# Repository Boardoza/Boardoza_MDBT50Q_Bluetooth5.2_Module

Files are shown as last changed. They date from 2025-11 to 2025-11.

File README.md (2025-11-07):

# Boardoza MDBT50Q Bluetooth Module

The **Boardoza MDBT50Q Bluetooth Module** is a high-performance wireless communication module based on the **Raytac MDBT50Q** series, featuring the **Nordic Semiconductor nRF52833 SoC** and supporting **Bluetooth 5.2**. This compact and power-efficient module is designed for applications requiring robust, long-range, and low-power wireless connectivity — such as IoT devices, smart home products, wearables, and industrial sensors.

It offers a UART communication interface and flexible configuration options, including selectable RC oscillators and hardware flow control. The MDBT50Q ensures reliability and ease of integration for developers working on BLE-enabled projects.

## [Click here to purchase!](https://www.ozdisan.com/p/gelistirme-kitleri-ve-aksesuarlari-617/boardoza-boardoza-mdbt50q-1202711)

|Front Side|Back Side|
|:---:|:---:|
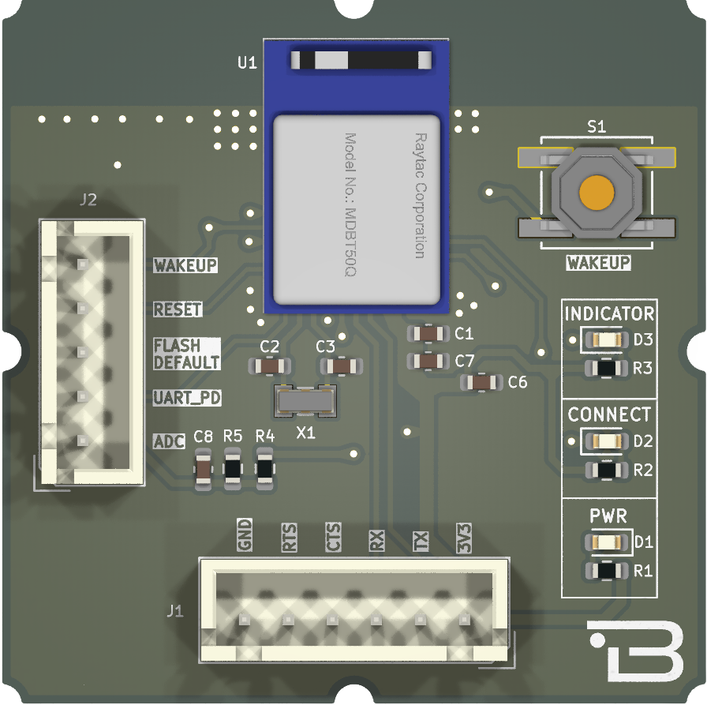
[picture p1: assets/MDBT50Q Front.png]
Front
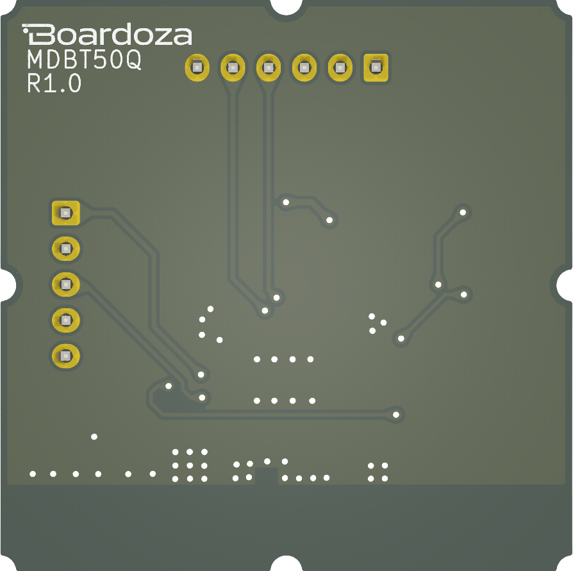
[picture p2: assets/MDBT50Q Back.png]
Back
|||

---

## **Key Features**

- **Bluetooth 5.2 Support:** Enables high-speed, low-energy communication with extended range.  
- **Nordic nRF52833 SoC:** Built-in ARM® Cortex®-M4 CPU with FPU operating up to 64 MHz.  
- **Low Power Consumption:** Optimized for long battery life in portable or IoT devices.  
- **Flexible UART Interface:** Configurable enable/disable control and flow control options.  
- **Selectable Clock Source:** Supports external or internal 32.768 kHz RC oscillator.  
- **512 KB RAM:** Large memory for advanced BLE applications.  

---

## **Technical Specifications**

**Manufacturer:** Raytac Corporation  
**Model:** MDBT50Q  
**Core Chip:** Nordic nRF52833 SoC (ARM® Cortex®-M4F)  
**Input Voltage:** 3.3V  
**Voltage Input Type:** Standard 6-pin header (2.54mm pitch)  
**Communication Interface:** UART  
**Bluetooth Version:** 5.2 (Low Energy)  
**Flash Memory:** 512 KB  
**RAM:** 128 KB  
**Antenna:** Integrated PCB antenna  
**Operating Frequency:** 2.4 GHz ISM band  
**Operating Temperature:** -40°C ~ +85°C  
**Extended Operating Temperature:** -40°C ~ +105°C 
**Board Dimensions:** 40mm x 40mm  
**Functions:** Bluetooth Low Energy Wireless Module  

---

## **Board Pinout**

### **( J1 ) Power & UART Connector**

| Pin Number | Pin Name | Description |
|:---:|:---:|---|
| 1 | 3V3 | Positive Power Supply |
| 2 | UART_TX | UART Transmitter |
| 3 | UART_RX | UART Receiver |
| 4 | UART_CTS | CTS, Clear to Send |
| 5 | UART_RTS | RTS, Request to Send |
| 6 | GND | Ground |

### **( J2 ) Control Connector**

| Pin Number | Pin Name | Description |
|:---:|:---:|---|
| 1 | ADC | 10-bit ADC input, updated every 200ms |
| 2 | UART_PD | Active-high with internal pull-up to disable UART hardware (default: disabled) |
| 3 | FLASH_DEFAULT | Active-low (0.48s ≤ Low ≤ 1s) triggers system reset to default configuration |
| 4 | RESET | Active-low system hardware reset |
| 5 | WAKEUP | Wake-up control output from deep sleep mode |

---

## **Board Dimensions**

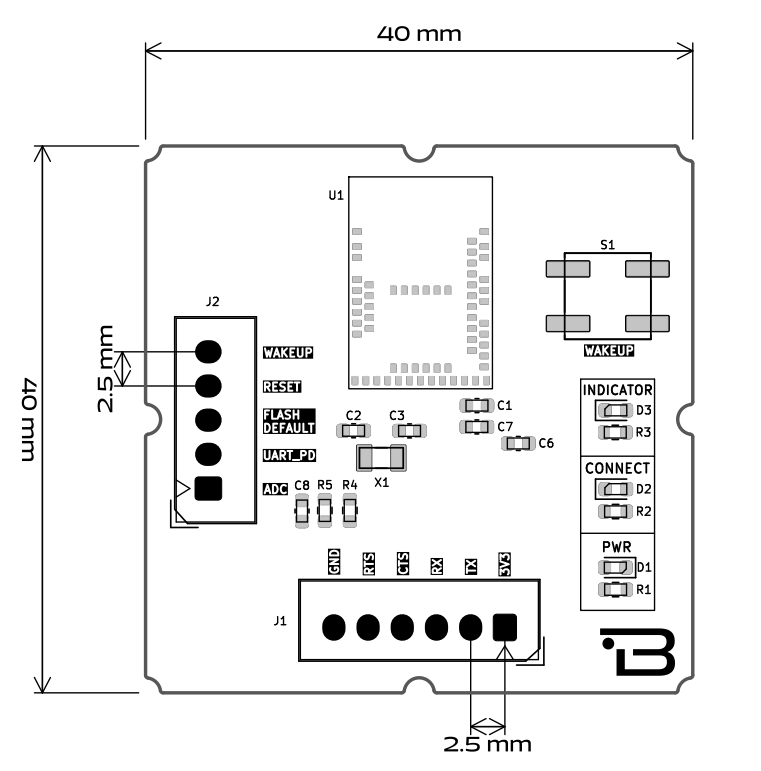
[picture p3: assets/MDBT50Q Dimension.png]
MDBT50Q Bluetooth Module Dimensions


---

## **Step Files**

[Boardoza MDBT50Q.step](./assets/MDBT50Q%20Step.step)

---

## **Datasheet**

[Raytac MDBT50Q Datasheet.pdf](./assets/MDBT50Q%20Datasheet.pdf)

---

## **Version History**

- V1.0.0 - Initial Release

---

## **Support**

For technical questions or assistance, please contact **<support@boardoza.com>**

---

## **License**

Shield: [][cc-by-sa]

This work is licensed under a [Creative Commons Attribution-ShareAlike 4.0 International License][cc-by-sa].

[][cc-by-sa]

[cc-by-sa]: http://creativecommons.org/licenses/by-sa/4.0/  
[cc-by-sa-image]: https://licensebuttons.net/l/by-sa/4.0/88x31.png  
[cc-by-sa-shield]: https://img.shields.io/badge/License-CC%20BY--SA%204.0-lightgrey.svg

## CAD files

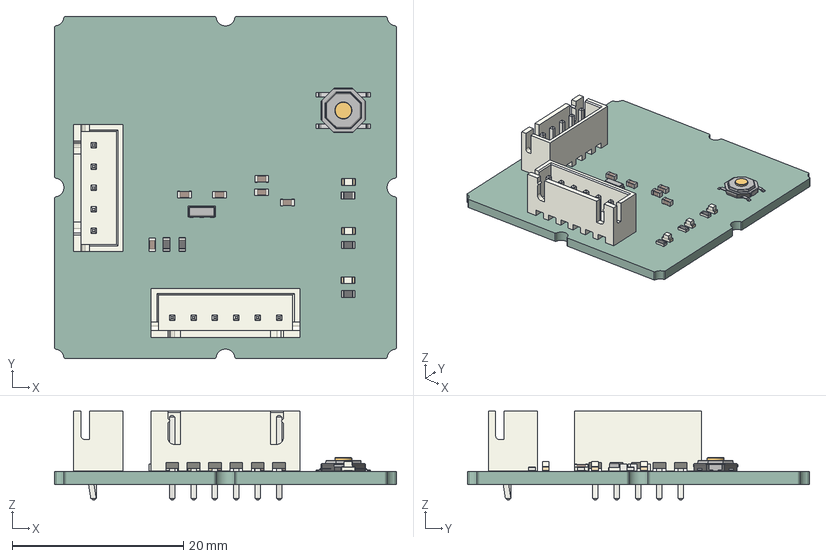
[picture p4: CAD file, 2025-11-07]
assets/MDBT50Q Step.step
40.0 x 40.0 x 10.4 mm
C_0603_1608Metric x 6
SW_SPST_TL3342
LED_0603_1608Metric x 3
JST_XH_B5B-XH-A_1x05_P2.50mm_Vertical
R_0603_1608Metric x 5
Resonator_SMD_muRata_CSTxExxV-3Pin_3.0x1.1mm
JST_XH_B6B-XH-A_1x06_P2.50mm_Vertical
B-MDBT50Q-ATMS-BRK_PCB

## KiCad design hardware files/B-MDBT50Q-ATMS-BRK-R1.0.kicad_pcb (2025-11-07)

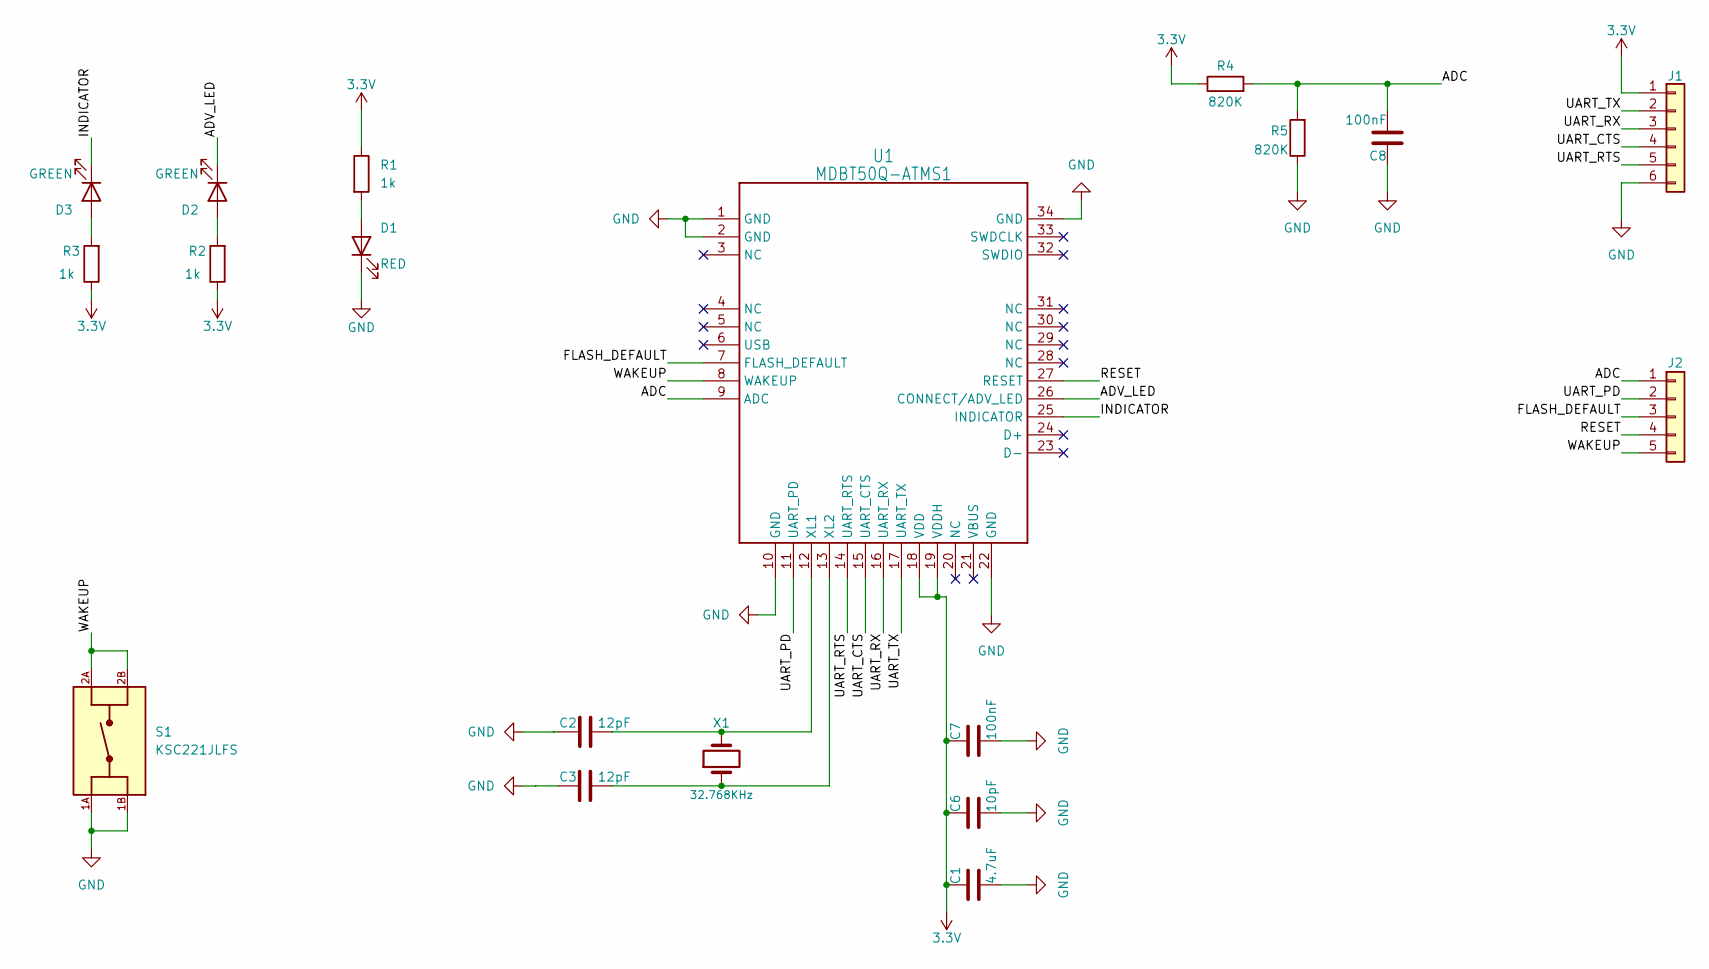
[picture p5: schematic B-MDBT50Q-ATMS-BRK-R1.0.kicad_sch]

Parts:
C1: 4.7uF; C_0603_1608Metric
C2, C3: 12pF; C_0603_1608Metric
C6: 10pF; C_0603_1608Metric
C7, C8: 100nF; C_0603_1608Metric
D1: RED; LED_0603_1608Metric
D2, D3: GREEN; LED_0603_1608Metric
J1: Conn_01x06; 2317-06S_1x06_P2.50mm_Vertical
J2: Conn_01x05; 2317-05S_1x05_P2.50mm_Vertical
R1, R2, R3: 1k; R_0603_1608Metric
R4, R5: 820K; R_0603_1608Metric
S1: KSC221JLFS; SW_KSC221JLFS; PARTREV 16 Mar 22
U1: MDBT50Q-ATMS1; MDBT50Q; MPN MDBT50Q-ATMS
X1: 32.768KHz; XTAL_CC7V-T1A-32.768K-9PF-20PPM-TB-QA; MPN FC-135 32.7680KA-AC3

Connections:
3.3V: C1.1, C6.1, C7.1, J1.1, R1.1, R2.1, R3.1, R4.1, U1.18 (VDD), U1.19 (VDDH)
/ADC: C8.2, J2.1, R4.2, R5.2, U1.9 (ADC)
/ADV_LED: D2.1 (K), U1.26 (CONNECT/ADV_LED)
/FLASH_DEFAULT: J2.3, U1.7 (FLASH_DEFAULT)
/INDICATOR: D3.1 (K), U1.25 (INDICATOR)
/RESET: J2.4, U1.27 (RESET)
/UART_CTS: J1.4, U1.15 (UART_CTS)
/UART_PD: J2.2, U1.11 (UART_PD)
/UART_RTS: J1.5, U1.14 (UART_RTS)
/UART_RX: J1.3, U1.16 (UART_RX)
/UART_TX: J1.2, U1.17 (UART_TX)
/WAKEUP: J2.5, S1.2A, S1.2B, U1.8 (WAKEUP)
GND: C1.2, C2.1, C3.1, C6.2, C7.2, C8.1, D1.1 (K), J1.6, R5.1, S1.1A, S1.1B, U1.1 (GND), U1.2 (GND), U1.10 (GND), U1.22 (GND), U1.34 (GND)
unnamed: D1.2 (A), R1.2
unnamed: D2.2 (A), R2.2
unnamed: D3.2 (A), R3.2
unnamed: C2.2, U1.12 (XL1), X1.2
unnamed: C3.2, U1.13 (XL2), X1.1

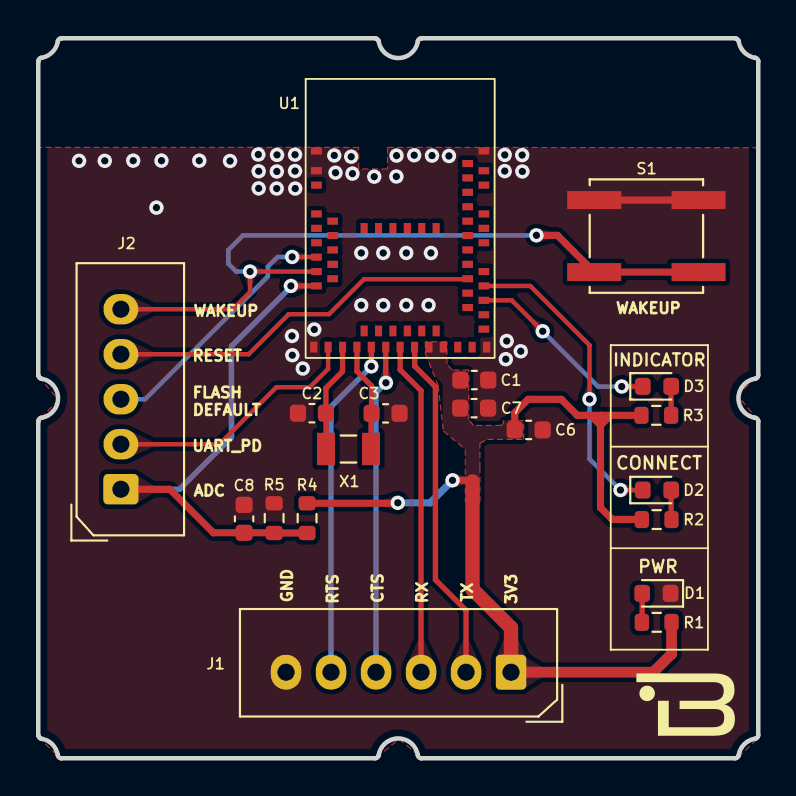
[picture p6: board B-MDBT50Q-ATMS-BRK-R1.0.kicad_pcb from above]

Board: 2 copper layers, 40.0 x 40.0 mm, 19 parts (0 on the bottom side), 18 nets.

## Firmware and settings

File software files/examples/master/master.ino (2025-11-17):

#include "Arduino.h"
#include "SoftwareSerial.h"

#define UART_PD 19
#define RESET 18
SoftwareSerial mySerial(21, 22);
void setup() {

  Serial.begin(9600);
  while(!Serial){

  }
  mySerial.begin(9600);
  pinMode(UART_PD, OUTPUT);
  pinMode(RESET, OUTPUT);
  digitalWrite(UART_PD, LOW);
  delay(20);

  digitalWrite(RESET, LOW);
  delayMicroseconds(20);
  digitalWrite(RESET, HIGH);
  delay(250);
  mySerial.println("AT+CENTRAL");
  delay(250);
  mySerial.println("AT+RESET");
  delay(250);
  mySerial.println("AT+SCANNEWSTART");
  delay(250);
  mySerial.println("AT++SCANNEWMACC06B4C744F5C");
  delay(250);
}

void loop() {

  while(Serial.available() > 0){ 
  mySerial.write(Serial.read()); 
  delay(1);  
  }
  while(mySerial.available() > 0){ 
  Serial.write(mySerial.read()); 
  delay(1);  
  }
}
